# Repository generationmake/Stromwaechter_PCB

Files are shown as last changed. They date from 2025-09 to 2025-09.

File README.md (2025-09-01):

# Stromwaechter
current and voltage monitor and power distribution for 12 V battery systems.

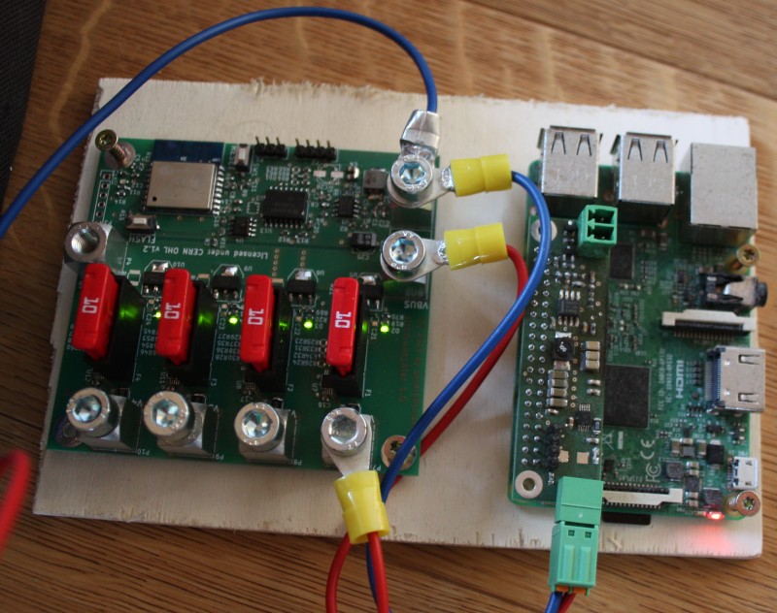
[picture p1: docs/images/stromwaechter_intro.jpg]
Stromwaechter intro


Stromwaechter on the left connected via WiFi to a Raspberry Pi 3 running OpenHAB on the right.

## Introduction

Stromwaechter is a pcb intended for power distribution and monitoring in remote hamradio stations. It has four channels with a dedicated fuse and a switch for each channel. On each channel current and voltage is monitored. The data is collected by an ESP8266 and transmitted via WiFi using the MQTT protocol. The board is intended to be used with a pc running OpenHAB for visualisation and logging but it may also be connected to any MQTT server.

## Hardware

The Stromwaechter has 4 output channels. Each channel can be switched by an Infineon ITS4200S. This IC has an internal over current and short circuit protection. Additionally each channel is protected by an ATO blade fuse. Also each channel has an TI INA226 to measure voltage and current on each channel. This allows to measure current in the range of -4.096 A to +4.096 A.

## Limitations

The stromwaechter PCB is intended to monitor current flowing from the bus connector to loads connected on each channel. It is also possible that current flows in the reverse direction from the output to the bus. In this case the internal short circuit and over current protections of the ITS4200S don't work anymore and there is a 600 mV voltage drop across the ITS4200S because of its internal diode.

## License

The hardware is released under CERN OHL v1.2

## Software

You can find the software on github: https://github.com/generationmake/stromwaechter
The software is released under GPL v3

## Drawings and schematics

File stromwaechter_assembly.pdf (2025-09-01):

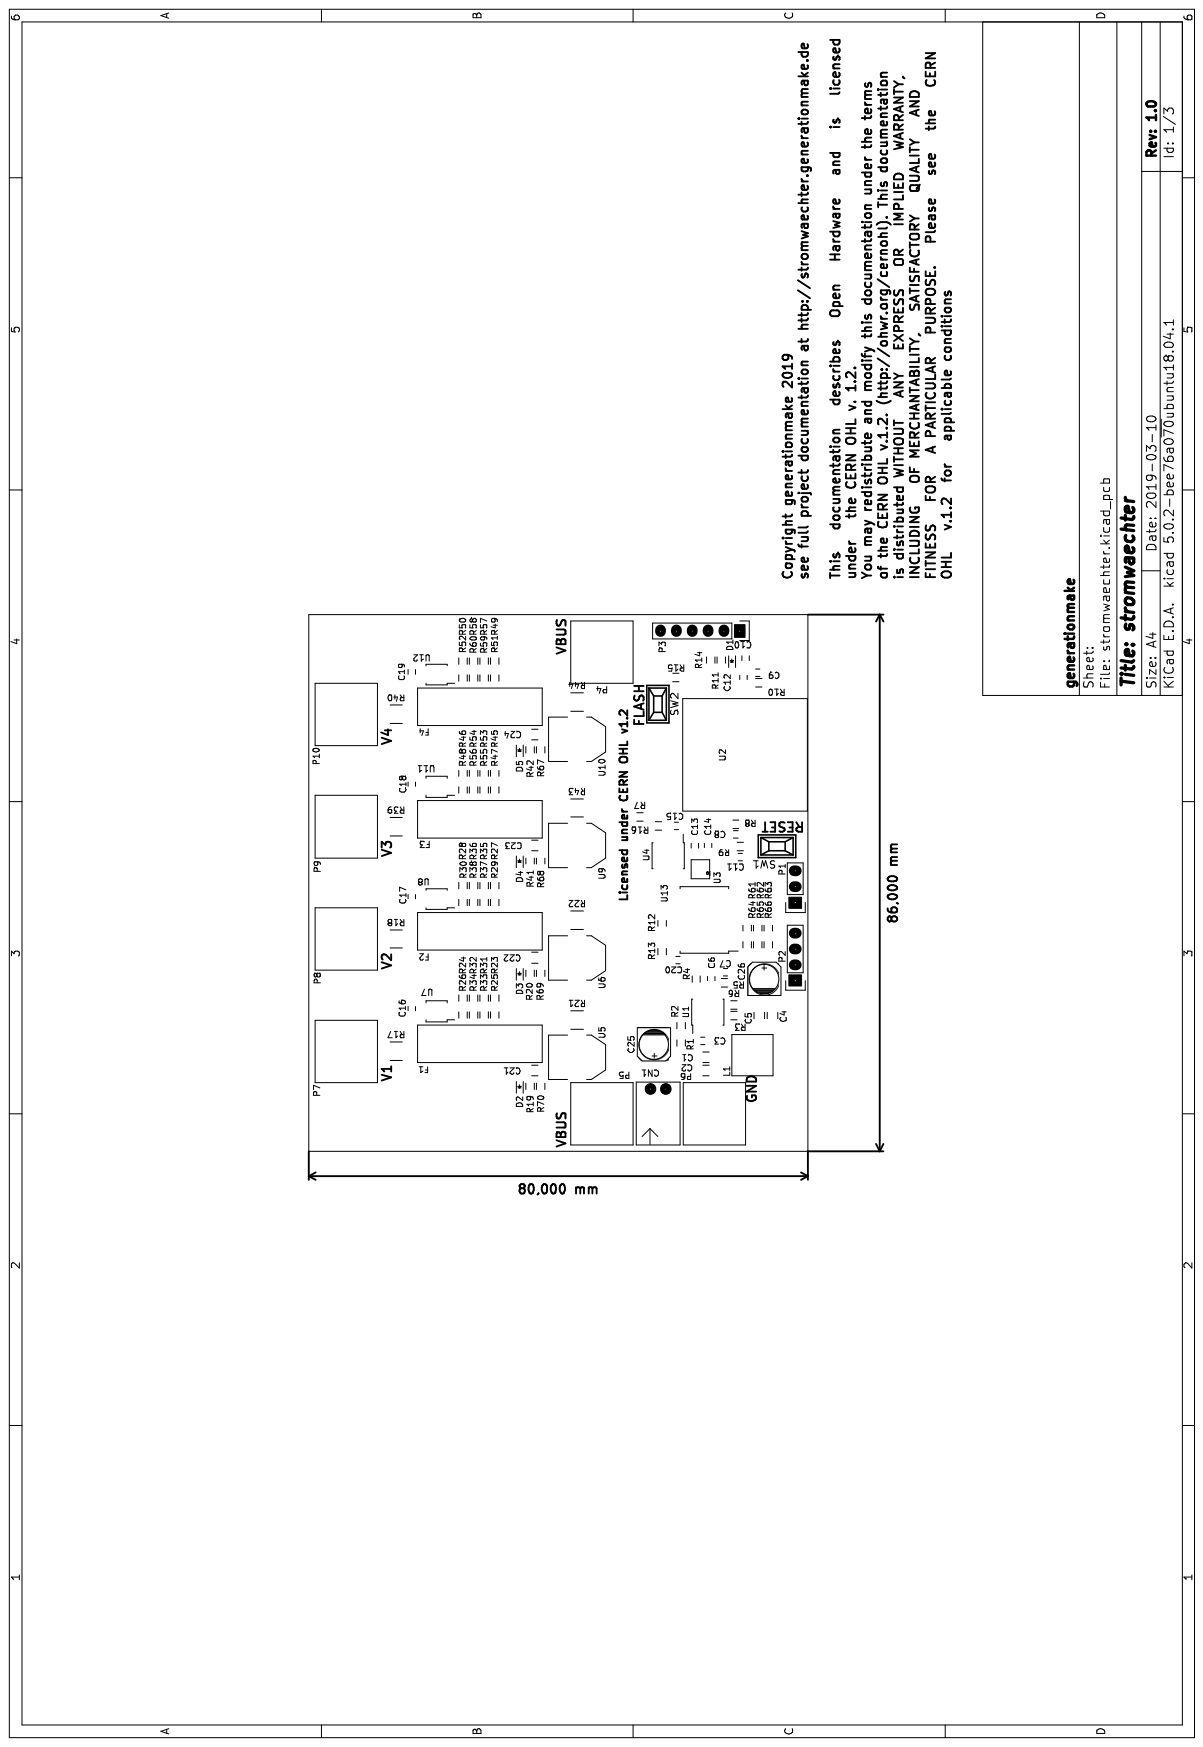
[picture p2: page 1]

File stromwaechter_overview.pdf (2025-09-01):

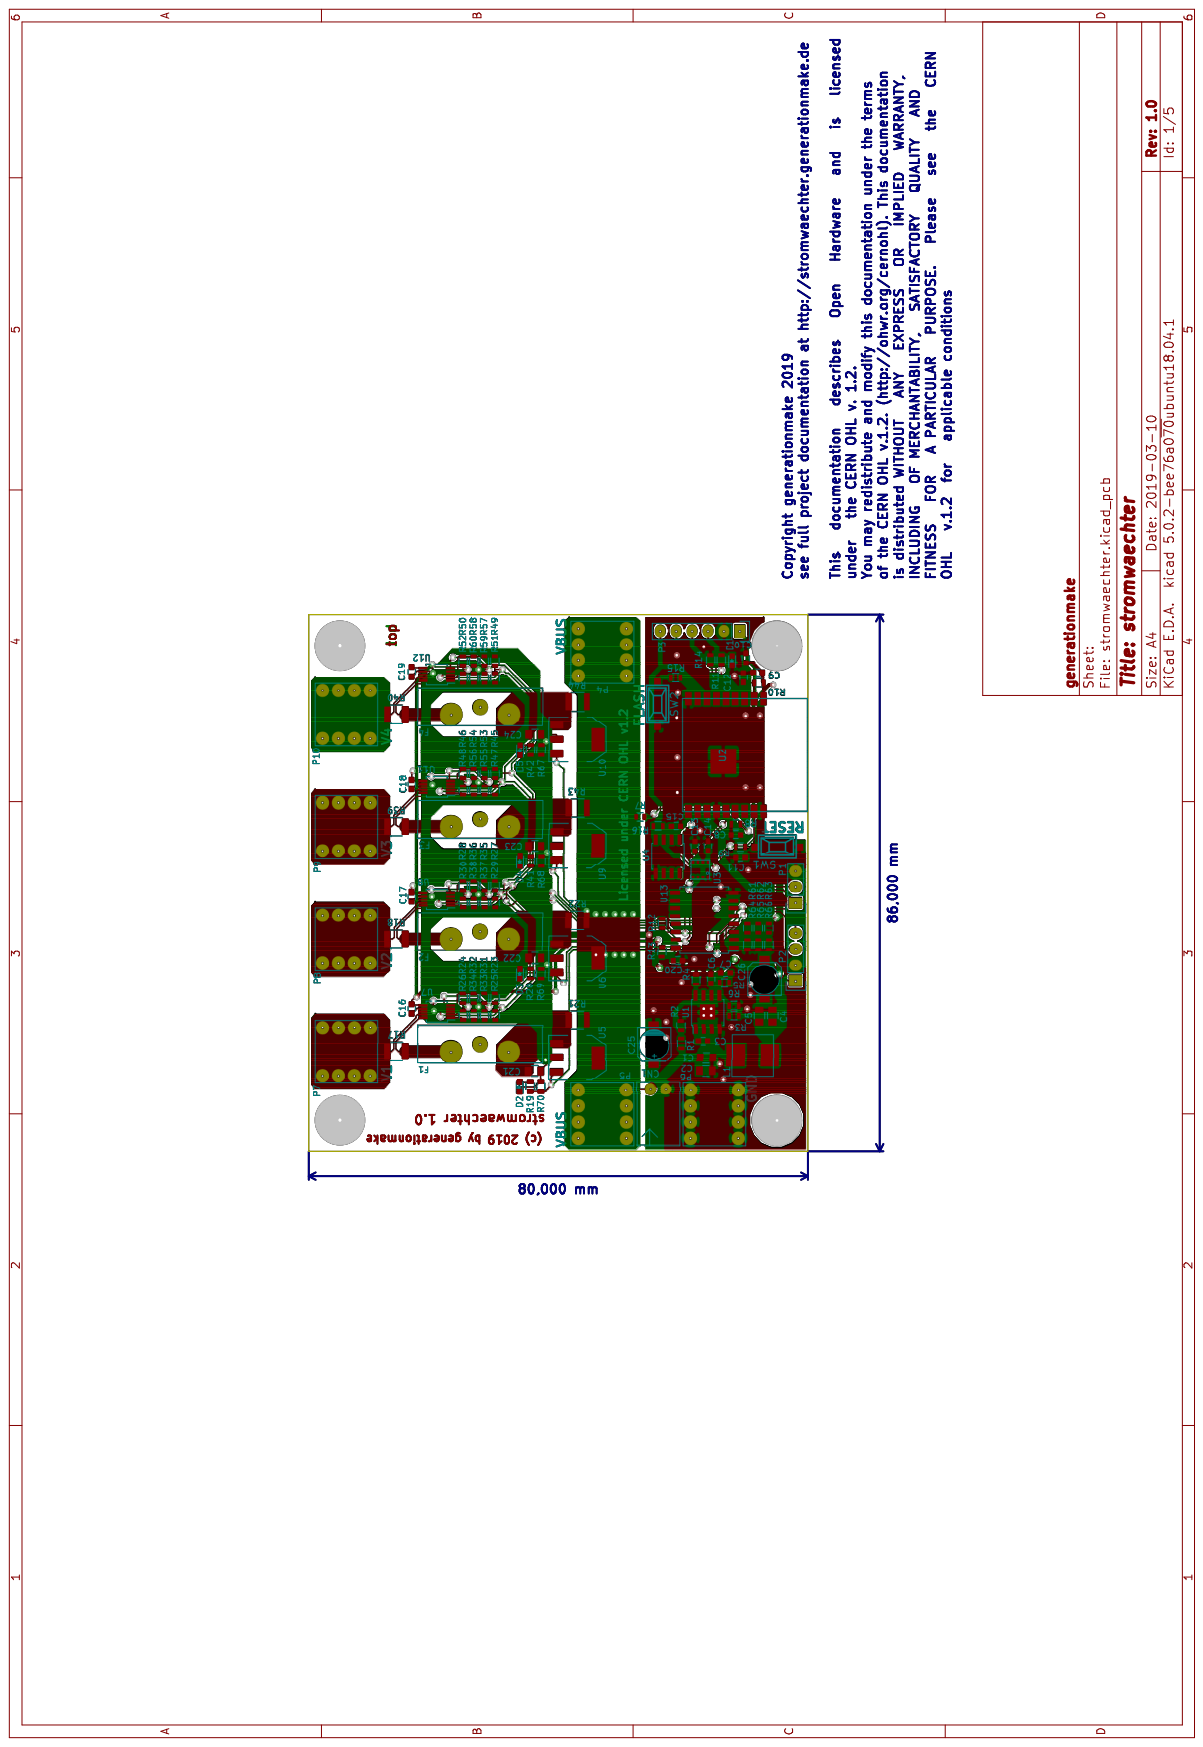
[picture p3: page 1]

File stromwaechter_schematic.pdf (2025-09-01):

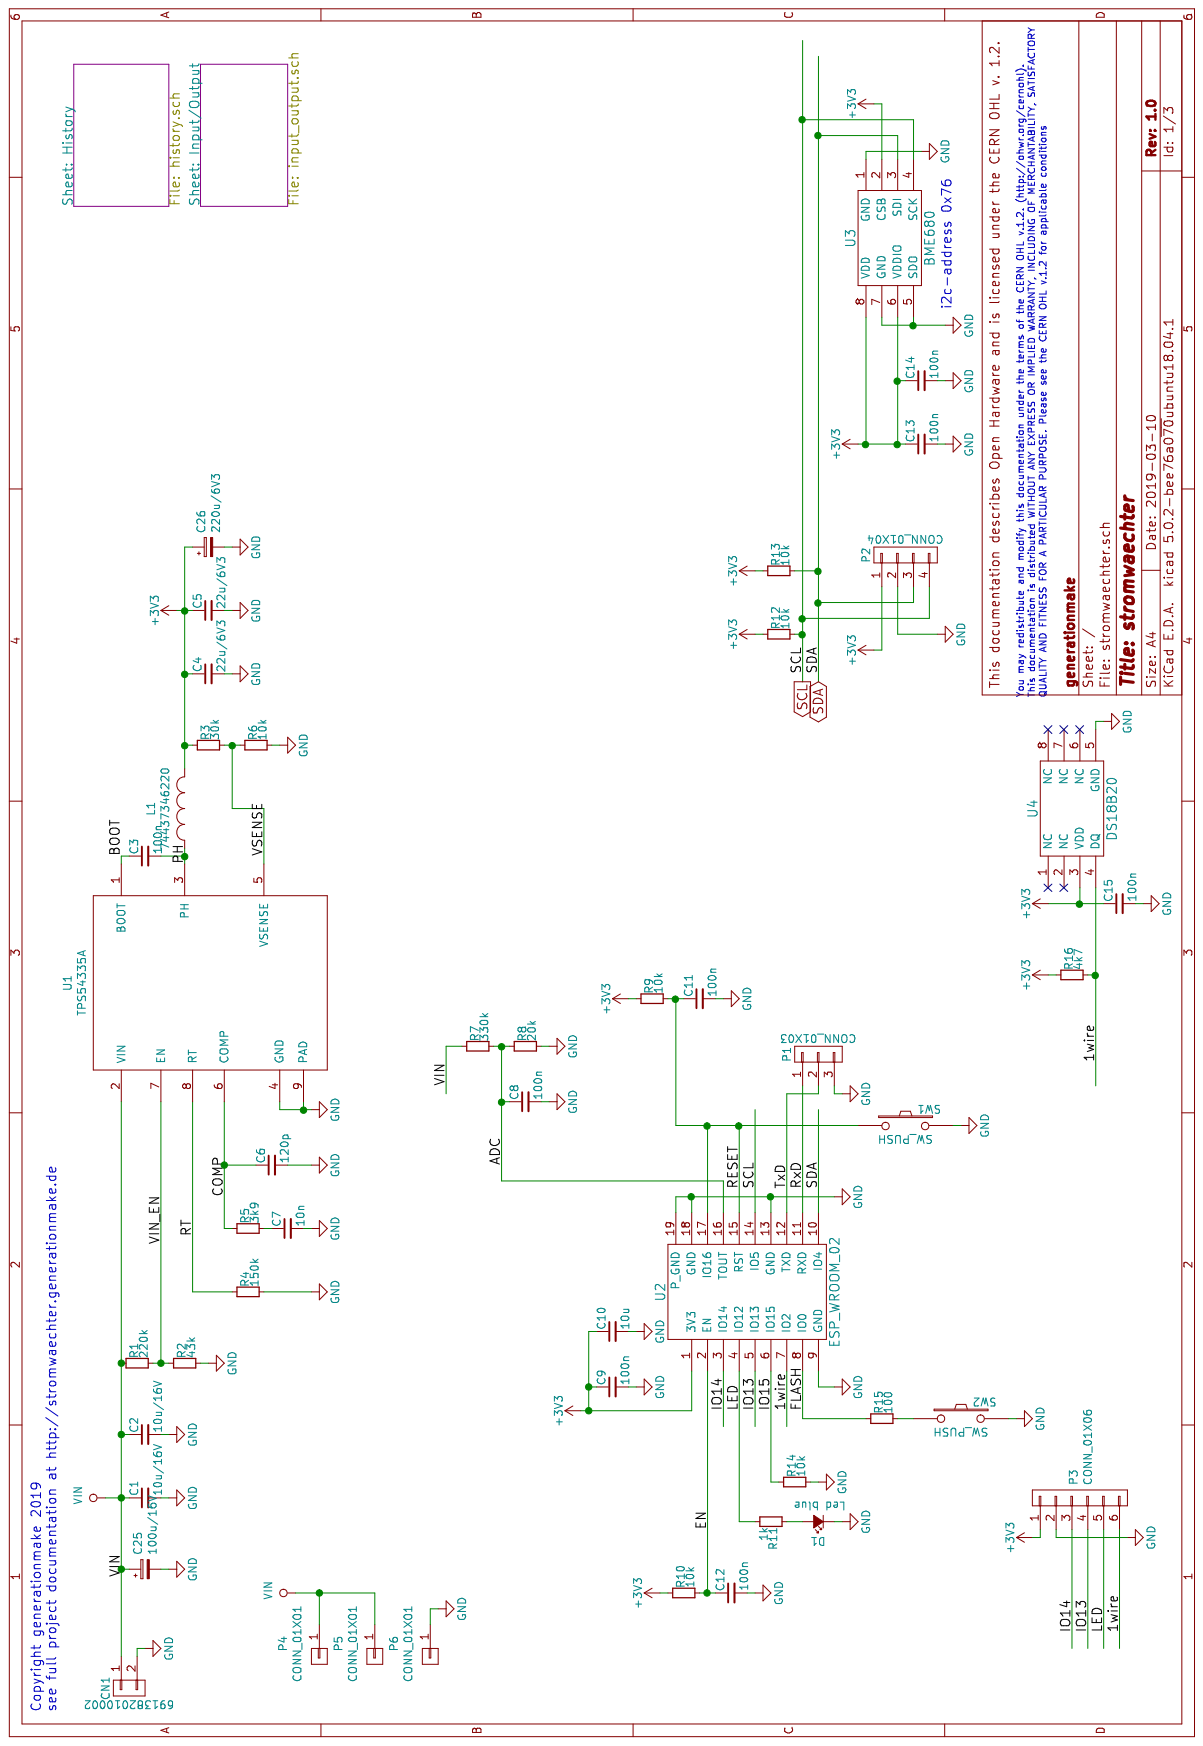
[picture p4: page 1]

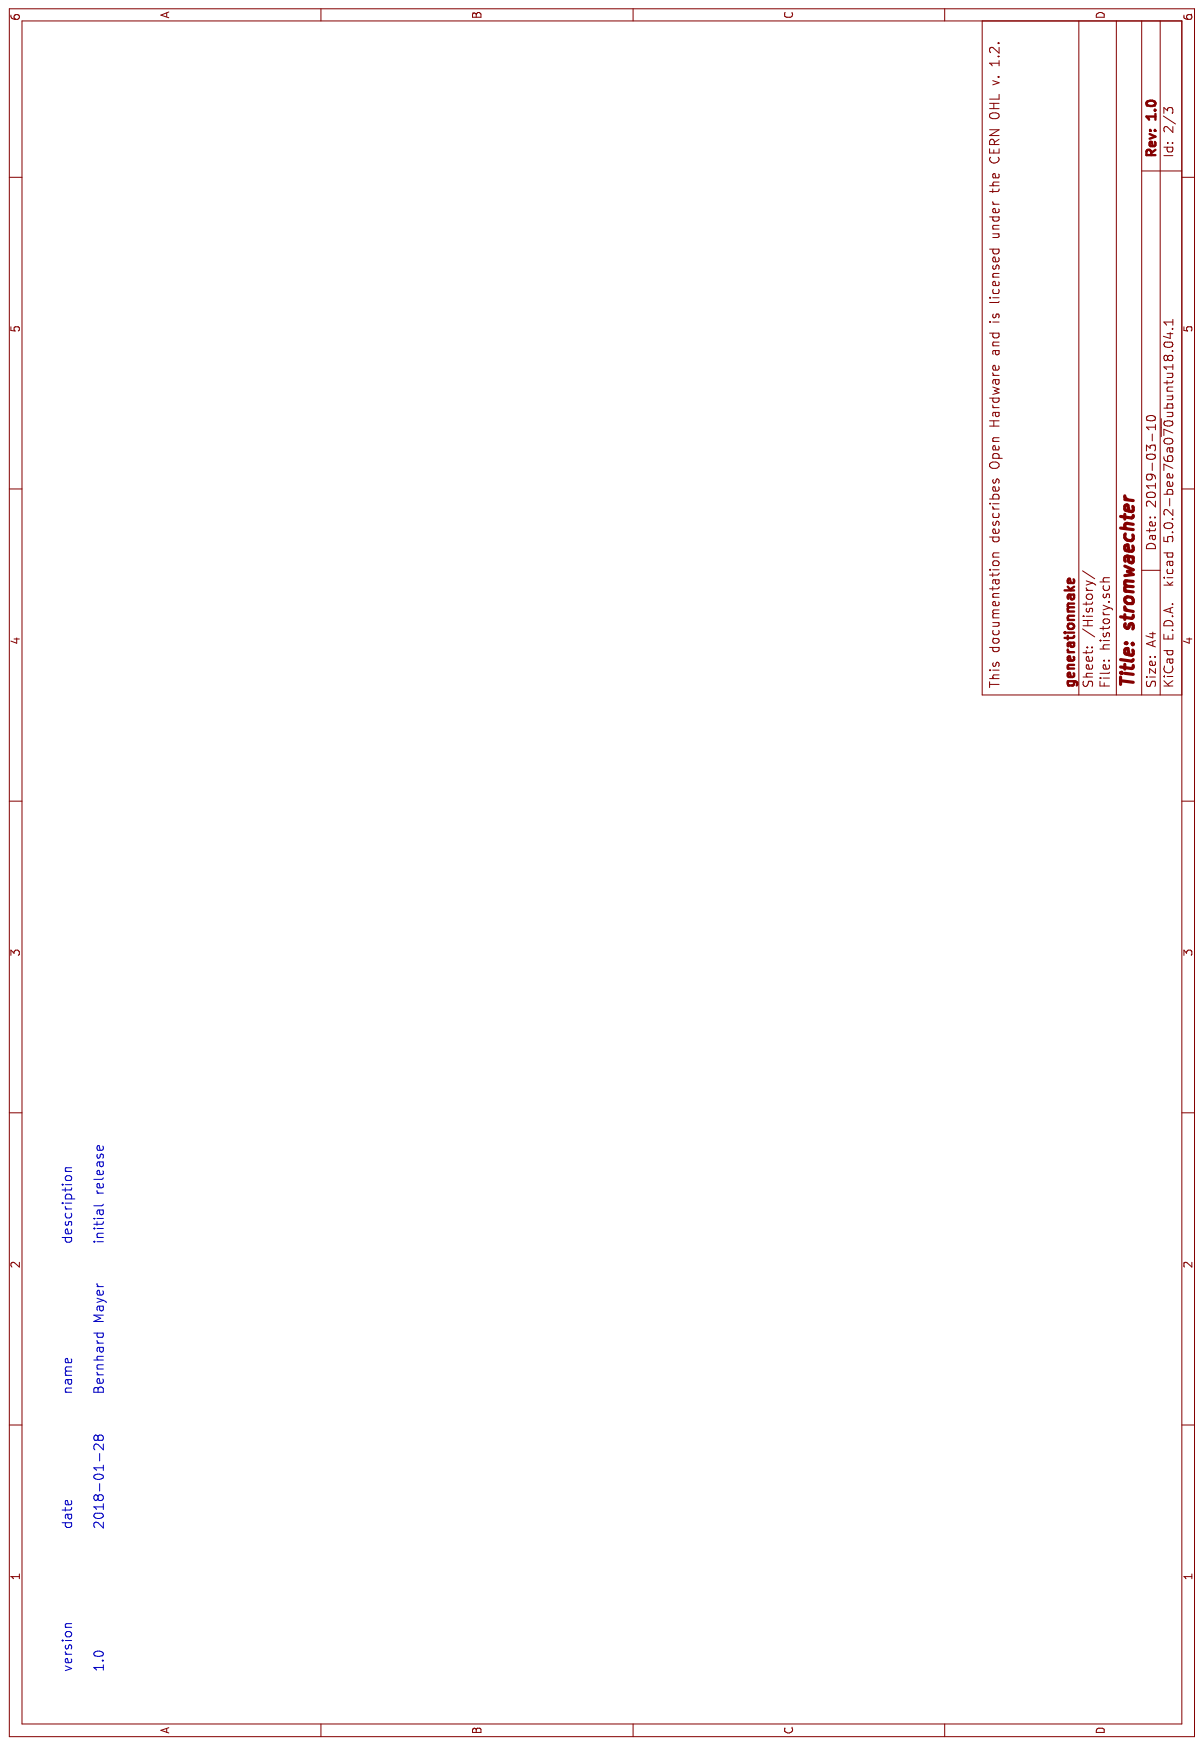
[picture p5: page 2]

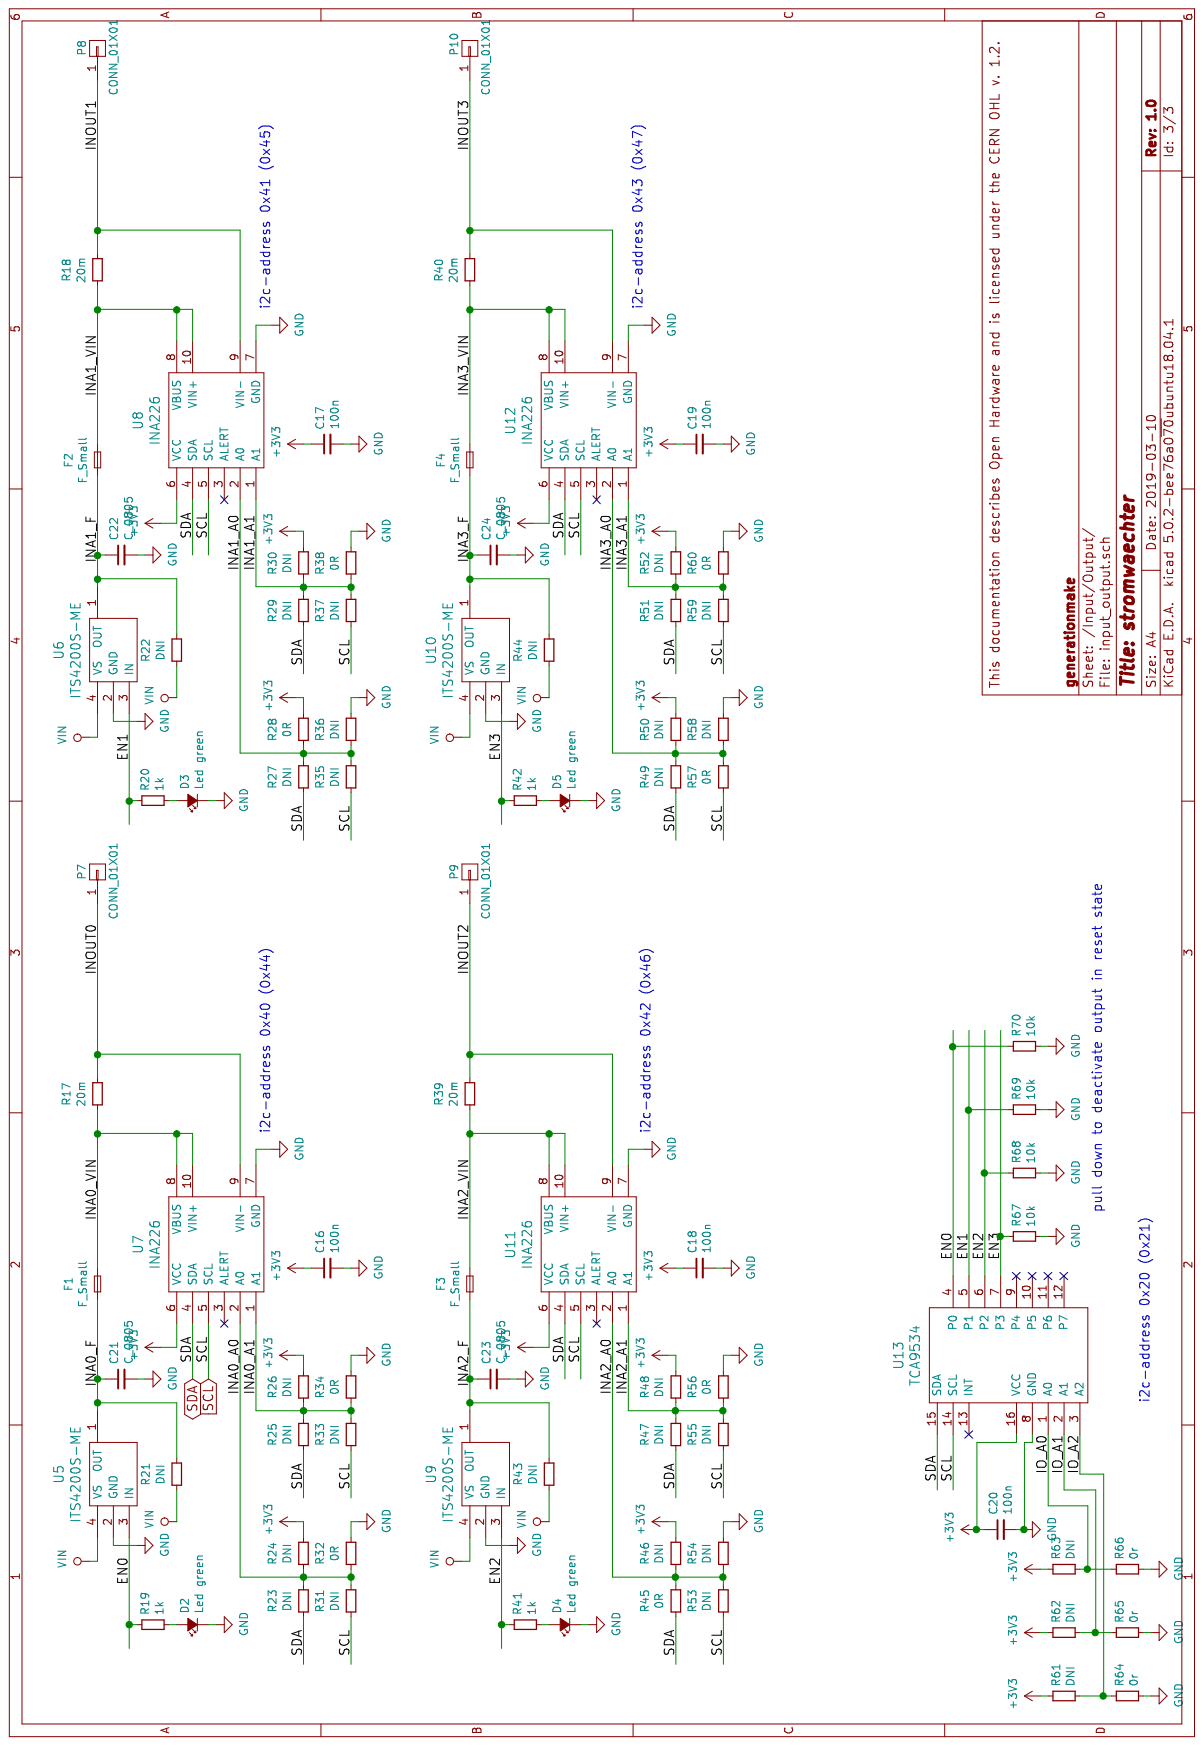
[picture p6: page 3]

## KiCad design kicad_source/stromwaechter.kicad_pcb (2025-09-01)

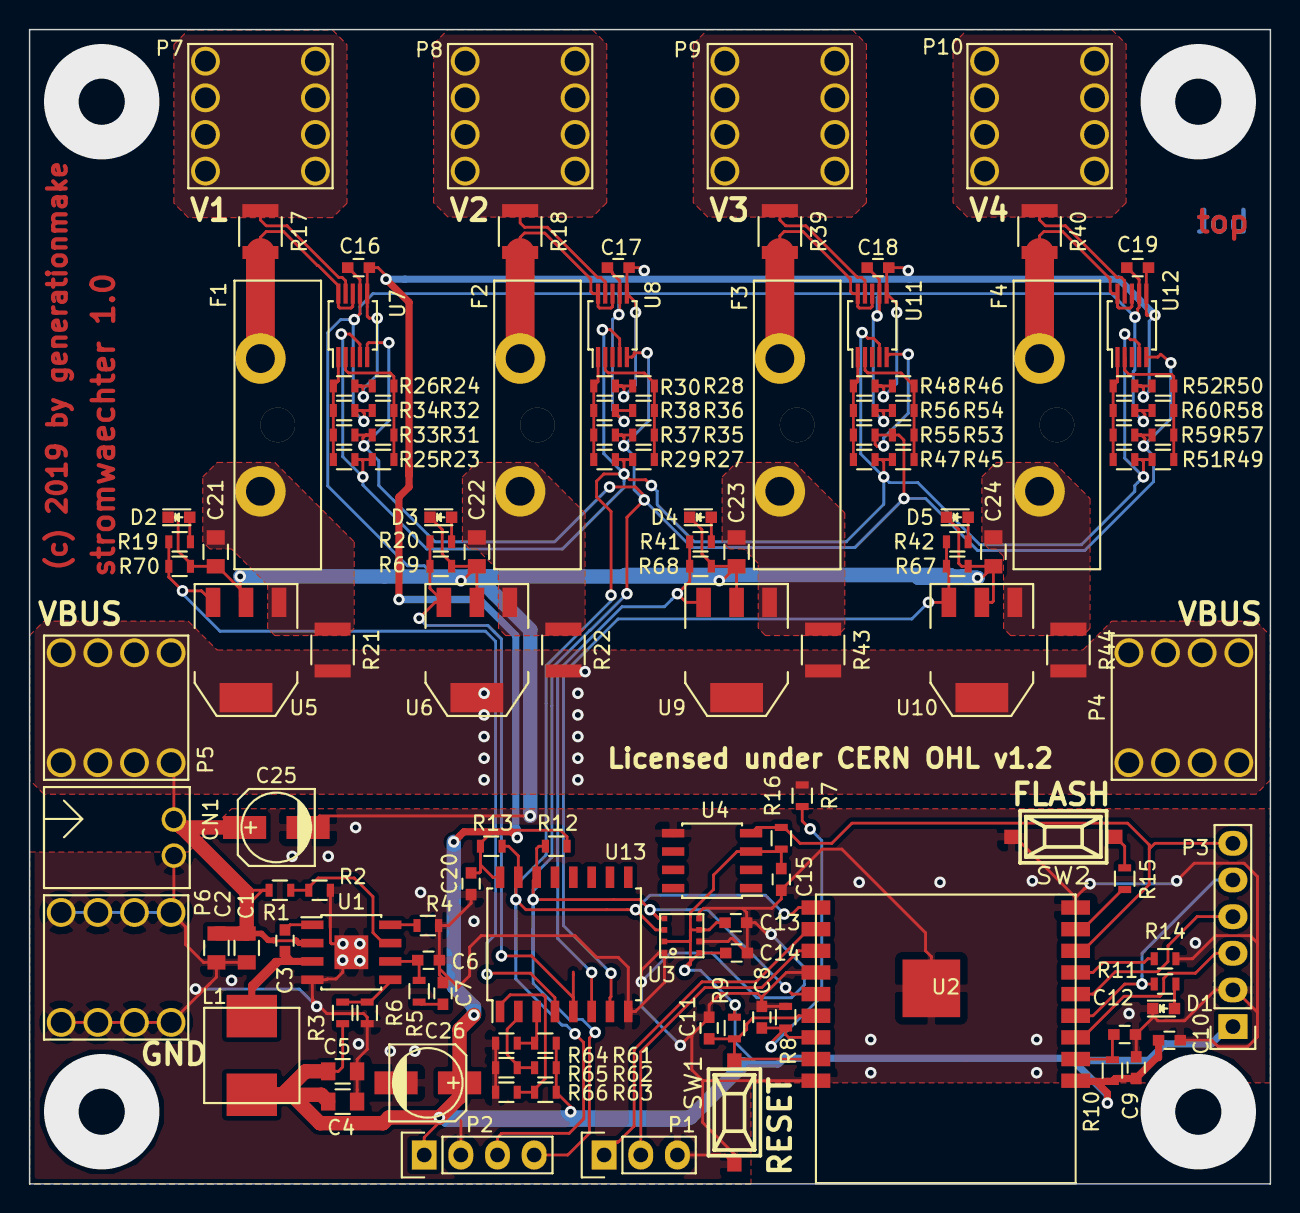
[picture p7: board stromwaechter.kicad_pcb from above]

Board: 2 copper layers, 86.0 x 80.0 mm, 132 parts (0 on the bottom side), 56 nets.

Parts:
C1, C2, C4, C5, C21, C22, C23, C24: C_0805
C3, C6, C7, C8, C9, C10, C11, C12, C13, C14, C15, C16, C17, C18, C19, C20: C_0603
C25, C26: CP_Small; c_elec_5x5.8
CN1: 691382010002; WR-TBL_691382010002
D1, D2, D3, D4, D5: Led_Small; LED_0603
F1, F2, F3, F4: F_Small; Fuseholder_ATO_Blade_littlefuse_Pudenz_2_Pin
L1: 74437346220; WE-LHMI70xx
P1: CONN_01X03; Pin_Header_Straight_1x03
P2: CONN_01X04; Pin_Header_Straight_1x04
P3: CONN_01X06; Pin_Header_Straight_1x06
P4, P5, P6, P7, P8, P9, P10: CONN_01X01; WP-BUTR_7461084
R1, R2, R3, R4, R5, R6, R7, R8, R9, R10, R11, R12, R13, R14, R15, R16, R19, R20, R23, R24, R25, R26, R27, R28, R29, R30, R31, R32, R33, R34, R35, R36, R37, R38, R41, R42, R45, R46, R47, R48, R49, R50, R51, R52, R53, R54, R55, R56, R57, R58, R59, R60, R61, R62, R63, R64, R65, R66, R67, R68, R69, R70: R_0603
R17, R18, R21, R22, R39, R40, R43, R44: R_1210
SW1, SW2: SW_PUSH; smd_push
U1: TPS54335A; SOIC-8-1EP_3.9x4.9mm_Pitch1.27mm
U2: ESP_WROOM_02; ESP-WROOM-02
U3: BME680
U4: DS18B20; SOIC-8_3.9x4.9mm_Pitch1.27mm
U5, U6, U9, U10: ITS4200S-ME; SOT-223
U7, U8, U11, U12: INA226; MSOP-10_3x3mm_Pitch0.5mm
U13: TCA9534; SOIC-16_7.5x10.3mm_Pitch1.27mm

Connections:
+3V3: C4.1, C5.1, C9.1, C10.1, C13.1, C14.1, C15.1, C16.1, C17.1, C18.1, C19.1, C20.1, C26.1, L1.2, P2.1, P3.1, R3.1, R9.1, R10.1, R12.1, R13.1, R16.1, R24.1, R26.1, R28.1, R30.1, R46.1, R48.1, R50.1, R52.1, R61.2, R62.2, R63.2, U2.1, U3.2, U3.6, U3.8, U4.3, U7.6, U8.6, U11.6, U12.6, U13.16
/1wire: P3.6, R16.2, U2.7, U4.4
/ADC: C8.1, R7.2, R8.1, U2.16
/BOOT: C3.1, U1.1
/COMP: C6.1, R5.1, U1.6
/EN: C12.1, R10.2, U2.2
/FLASH: R15.1, U2.8
/IO13: P3.4, U2.5
/IO14: P3.3, U2.3
/IO15: R14.1, U2.6
/Input/Output/EN0: R19.2, R70.2, U5.3, U13.4
/Input/Output/EN1: R20.2, R69.2, U6.3, U13.5
/Input/Output/EN2: R41.2, R68.2, U9.3, U13.6
/Input/Output/EN3: R42.2, R67.2, U10.3, U13.7
/Input/Output/INA0_A0: R23.1, R24.2, R31.1, R32.2, U7.2
/Input/Output/INA0_A1: R25.1, R26.2, R33.1, R34.2, U7.1
/Input/Output/INA0_F: C21.1, F1.1, R21.1, U5.1
/Input/Output/INA0_VIN: F1.2, R17.2, U7.8, U7.10
/Input/Output/INA1_A0: R27.1, R28.2, R35.1, R36.2, U8.2
/Input/Output/INA1_A1: R29.1, R30.2, R37.1, R38.2, U8.1
/Input/Output/INA1_F: C22.1, F2.1, R22.1, U6.1
/Input/Output/INA1_VIN: F2.2, R18.2, U8.8, U8.10
/Input/Output/INA2_A0: R45.1, R46.2, R53.1, R54.2, U11.2
/Input/Output/INA2_A1: R47.1, R48.2, R55.1, R56.2, U11.1
/Input/Output/INA2_F: C23.1, F3.1, R43.1, U9.1
/Input/Output/INA2_VIN: F3.2, R39.2, U11.8, U11.10
/Input/Output/INA3_A0: R49.1, R50.2, R57.1, R58.2, U12.2
/Input/Output/INA3_A1: R51.1, R52.2, R59.1, R60.2, U12.1
/Input/Output/INA3_F: C24.1, F4.1, R44.1, U10.1
/Input/Output/INA3_VIN: F4.2, R40.2, U12.8, U12.10
/Input/Output/INOUT0: P7.1, R17.1, U7.9
/Input/Output/INOUT1: P8.1, R18.1, U8.9
/Input/Output/INOUT2: P9.1, R39.1, U11.9
/Input/Output/INOUT3: P10.1, R40.1, U12.9
/Input/Output/IO_A0: R63.1, R66.2, U13.1
/Input/Output/IO_A1: R62.1, R65.2, U13.2
/Input/Output/IO_A2: R61.1, R64.2, U13.3
/LED: P3.5, R11.2, U2.4
/PH: C3.2, L1.1, U1.3
/RESET: C11.1, R9.2, SW1.1, U2.15, U2.17
/RT: R4.1, U1.8
/RxD: P1.1, U2.11
/TxD: P1.2, U2.12
/VIN_EN: R1.2, R2.1, U1.7
/VSENSE: R3.2, R6.1, U1.5
GND: C1.2, C2.2, C4.2, C5.2, C6.2, C7.2, C8.2, C9.2, C10.2, C11.2, C12.2, C13.2, C14.2, C15.2, C16.2, C17.2, C18.2, C19.2, C20.2, C21.2, C22.2, C23.2, C24.2, C25.2, C26.2, CN1.2, D1.1, D2.1, D3.1, D4.1, D5.1, P1.3, P2.2, P3.2, P6.1, R2.2, R4.2, R6.2, R8.2, R14.2, R32.1, R34.1, R36.1, R38.1, R54.1, R56.1, R58.1, R60.1, R64.1, R65.1, R66.1, R67.1, R68.1, R69.1, R70.1, SW1.2, SW2.2, U1.4, U1.9, U2.9, U2.13, U2.18, U2.19, U3.1, U3.5, U3.7, U4.5, U5.2, U6.2, U7.7, U8.7, U9.2, U10.2, U11.7, U12.7, U13.8
unnamed: C7.1, R5.2
unnamed: D1.2, R11.1
unnamed: D2.2, R19.1
unnamed: D3.2, R20.1
unnamed: D4.2, R41.1
unnamed: D5.2, R42.1
unnamed: R15.2, SW2.1
SCL: P2.4, R12.2, R31.2, R33.2, R35.2, R37.2, R53.2, R55.2, R57.2, R59.2, U2.14, U3.4, U7.5, U8.5, U11.5, U12.5, U13.14
SDA: P2.3, R13.2, R23.2, R25.2, R27.2, R29.2, R45.2, R47.2, R49.2, R51.2, U2.10, U3.3, U7.4, U8.4, U11.4, U12.4, U13.15
VIN: C1.1, C2.1, C25.1, CN1.1, P4.1, P5.1, R1.1, R7.1, R21.2, R22.2, R43.2, R44.2, U1.2, U5.4, U6.4, U9.4, U10.4

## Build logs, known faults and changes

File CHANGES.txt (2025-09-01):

Stromwaechter - current and voltage monitor and power distribution

bernhard@generationmake.de
see full project documentation at http://stromwaechter.generationmake.de

changes

version 1.0 - 2019-03-10
* initial release

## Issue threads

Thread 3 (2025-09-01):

use screwless terminal blocks for battery cables

generationmake, 2025-09-01:
for example WAGO 2606 or 2616.

https://www.wago.com/global/pcb-terminal-blocks-and-pluggable-connectors/pcb-terminal-block/p/2606-1102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
https://www.wago.com/global/pcb-terminal-blocks-and-pluggable-connectors/pcb-terminal-block/p/2616-1102_020-000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

Is rated for at least 31 A and should be OK.

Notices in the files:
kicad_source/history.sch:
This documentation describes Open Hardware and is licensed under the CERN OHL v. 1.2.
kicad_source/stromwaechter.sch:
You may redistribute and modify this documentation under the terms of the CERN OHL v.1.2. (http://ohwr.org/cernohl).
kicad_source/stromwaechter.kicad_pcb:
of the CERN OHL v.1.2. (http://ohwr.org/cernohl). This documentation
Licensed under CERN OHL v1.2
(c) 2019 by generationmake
